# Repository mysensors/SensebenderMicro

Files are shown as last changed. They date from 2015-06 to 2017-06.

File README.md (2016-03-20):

# Sensebender Micro

This is a micro sensor module for Mysensors project: http://www.mysensors.org

Designed to run on 2 x AA(A) batteries, depending on how often one would
like to replace the batteries. 

The sensor includes the following peripherals

- Si7021 Temperature / Humidity sensor (Connected to I2C bus)
- Jedec compatible eeprom/flash footprint
- ATSHA204A for authentication
- LED

The following pins are available on headers:

- Powersupply (1.8 -> 3.5V)
- SDA / SCL (I2C bus)
- A0 / A1
- D3 / D4 / D5 / D6 / D7
- 6 pin ISP port
- 8 pin standard NRF24L01+ connector layout
- FTDI header for serial

*Please note*

MAXIMUM allowed supply voltage is 3.5V, anything above this WILL fry both
Si7021, flash and NRF24 radio module. There is NO voltage regulator on board (To keep
supply current down to a minimum)

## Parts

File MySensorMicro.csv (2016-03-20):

Qty | Value | Device | Package | Parts | Description | MF | MPN
1 |  | LED-0402 | LED-0402 | D1 |  | Vishay | VLMO1500-GS08
0 | NM | M05NO_SILK | 1X05_NO_SILK | JP4 | Not mounted
0 | NM | M06NO_SILK_FEMALE_PTH | 1X06_NO_SILK | JP2, JP5 | Not mounted
5 | 100n | CAP-0402 | C0402 | C1, C2, C4, C5, C6 | Ceramic Capacitors
1 | 10k | R-0402 | R0402 | R3
0 | 32768hz | CRYSTAL-306010055 | 2P-L3.2XW1.5MM | Q1 | Not mounted
1 | 330 | R-0402 | R0402 | R4
2 | 4k7 | R-0402 | R0402 | R1, R2
2 | 56k | R-0402 | R0402 | R5, R6
1 | 4u7 | CAP-0603 | C0603 | C3 | Ceramic Capacitors
1 | AT25DF512C-SSHN-B | AT25DF512C-SSHN-B | SO-08 | IC2 | Flash 512K, 1.65V, 85Mhz Serial Flash | Adesto | AT25DF512C-SSHN-B
1 | ATSHA204A | ATSHA204A | SOT23 | IC4 |  | Atmel | ATSHA204A-STUCZ-T
0 | NM | AVR-ISP-6VERT | AVR-ISP-6 | JP3 | Not mounted
1 | MEGA328P-AU | MEGA48/88/168-AU | TQFP32-08 | IC1 |  | Atmel | ATMEGA328P-AU
0 | NM | PINHD-2X4 | 2X04 | JP1 | Not mounted
1 | SI7021 | SI7021 | DFN6 | IC3 |  | Silicon Labs | Si7021-A20-GM1

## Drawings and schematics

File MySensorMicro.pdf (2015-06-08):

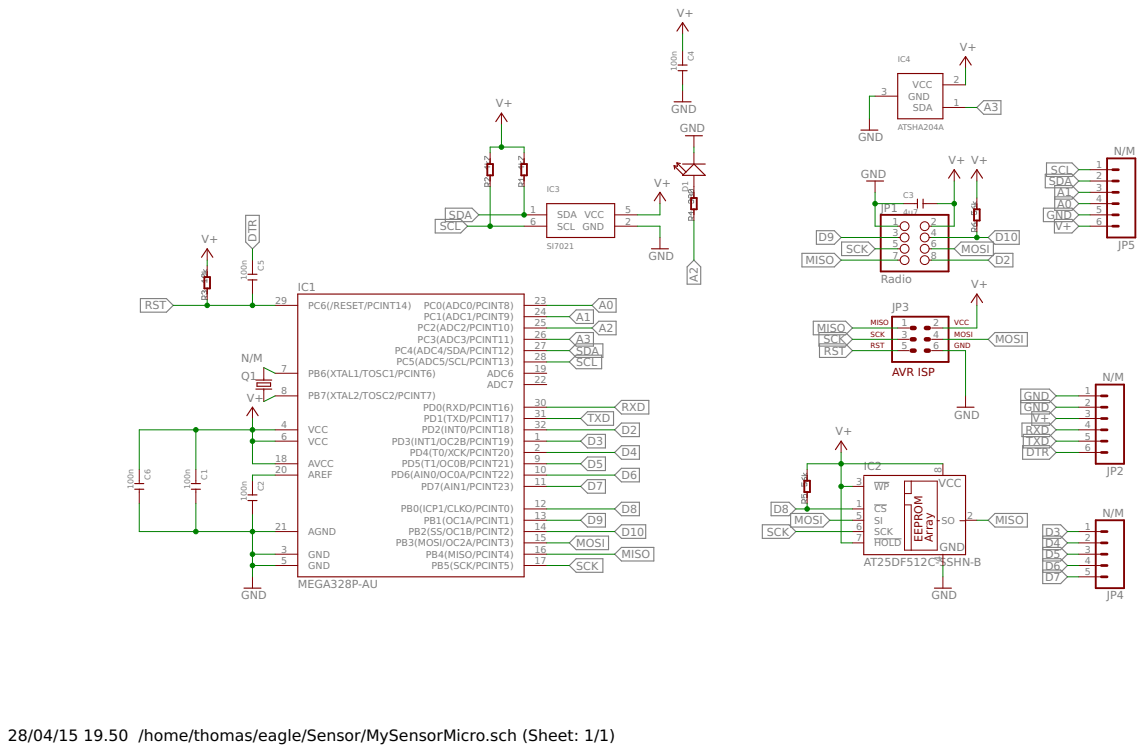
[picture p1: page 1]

2 HOLD

28/04/15 19.50 /home/thomas/eagle/Sensor/MySensorMicro.sch (Sheet: 1/1)

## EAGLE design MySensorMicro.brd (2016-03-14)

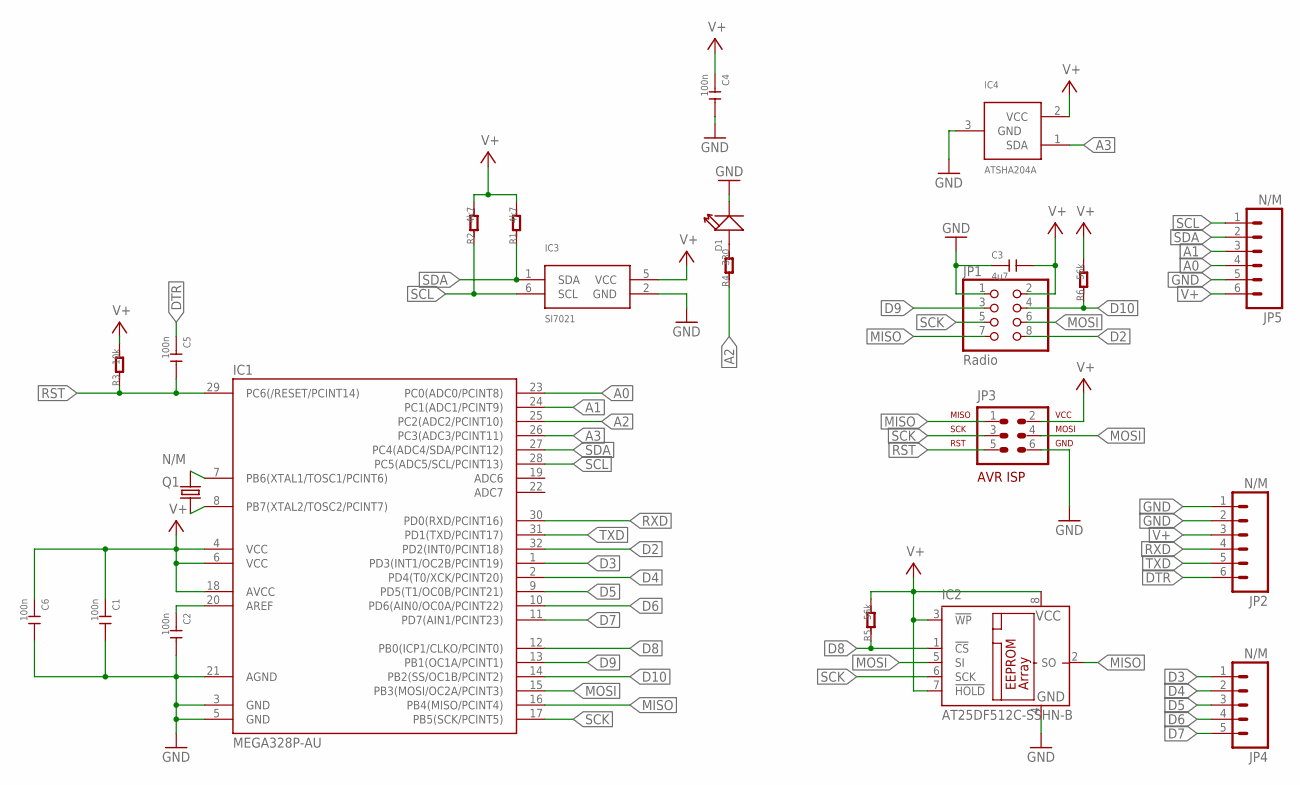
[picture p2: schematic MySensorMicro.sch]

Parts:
C1, C2, C4, C5, C6: 100n; C0402
C3: 4u7; C0603
D1: LED-0402
IC1: MEGA328P-AU; TQFP32-08
IC2: AT25DF512C-SSHN-B; SO-08
IC3: SI7021; DFN6
IC4: ATSHA204A; SOT23
JP1: Radio; 2X04
JP2, JP5: N/M; 1X06_NO_SILK
JP3: N/M; AVR-ISP-6
JP4: N/M; 1X05_NO_SILK
Q1: N/M; 2P-L3.2XW1.5MM
R1, R2: 4k7; R0402
R3: 10k; R0402
R4: 330; R0402
R5, R6: 56k; R0402

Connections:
A0: IC1.23 (PC0(ADC0/PCINT8)), JP5.4
A1: IC1.24 (PC1(ADC1/PCINT9)), JP5.3
A2: IC1.25 (PC2(ADC2/PCINT10)), R4.1
A3: IC1.26 (PC3(ADC3/PCINT11)), IC4.1 (SDA)
D2: IC1.32 (PD2(INT0/PCINT18)), JP1.8
D3: IC1.1 (PD3(INT1/OC2B/PCINT19)), JP4.1
D4: IC1.2 (PD4(T0/XCK/PCINT20)), JP4.2
D5: IC1.9 (PD5(T1/OC0B/PCINT21)), JP4.3
D6: IC1.10 (PD6(AIN0/OC0A/PCINT22)), JP4.4
D7: IC1.11 (PD7(AIN1/PCINT23)), JP4.5
D8: IC1.12 (PB0(ICP1/CLKO/PCINT0)), IC2.1 (!CS), R5.1
D9: IC1.13 (PB1(OC1A/PCINT1)), JP1.3
D10: IC1.14 (PB2(SS/OC1B/PCINT2)), JP1.4, R6.1
DTR: C5.1, JP2.6
GND: C1.2, C2.2, C3.1, C4.2, C6.2, D1.-, IC1.3 (GND), IC1.5 (GND), IC1.21 (AGND), IC2.4 (GND), IC3.2 (GND), IC4.3 (GND), JP1.1, JP2.1, JP2.2, JP3.6, JP5.5
MISO: IC1.16 (PB4(MISO/PCINT4)), IC2.2 (SO), JP1.7, JP3.1
MOSI: IC1.15 (PB3(MOSI/OC2A/PCINT3)), IC2.5 (SI), JP1.6, JP3.4
unnamed: IC1.7 (PB6(XTAL1/TOSC1/PCINT6)), Q1.1
unnamed: IC1.8 (PB7(XTAL2/TOSC2/PCINT7)), Q1.2
unnamed: D1.+, R4.2
unnamed: C2.1, IC1.20 (AREF)
RST: C5.2, IC1.29 (PC6(/RESET/PCINT14)), JP3.5, R3.1
RXD: IC1.30 (PD0(RXD/PCINT16)), JP2.4
SCK: IC1.17 (PB5(SCK/PCINT5)), IC2.6 (SCK), JP1.5, JP3.3
SCL: IC1.28 (PC5(ADC5/SCL/PCINT13)), IC3.6 (SCL), JP5.1, R2.1
SDA: IC1.27 (PC4(ADC4/SDA/PCINT12)), IC3.1 (SDA), JP5.2, R1.1
TXD: IC1.31 (PD1(TXD/PCINT17)), JP2.5
V+: C1.1, C3.2, C4.1, C6.1, IC1.4 (VCC), IC1.6 (VCC), IC1.18 (AVCC), IC2.3 (!WP), IC2.7 (!HOLD), IC2.8 (VCC), IC3.5 (VCC), IC4.2 (VCC), JP1.2, JP2.3, JP3.2, JP5.6, R1.2, R2.2, R3.2, R5.2, R6.2

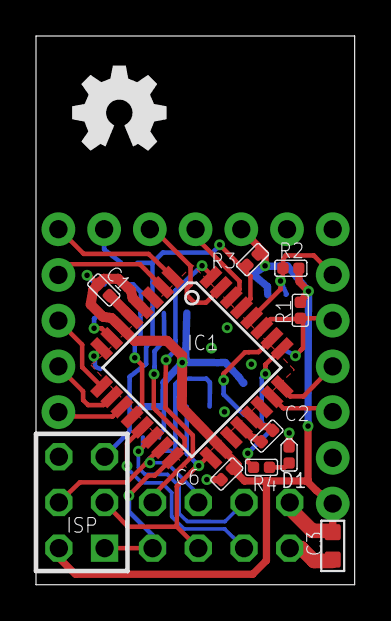
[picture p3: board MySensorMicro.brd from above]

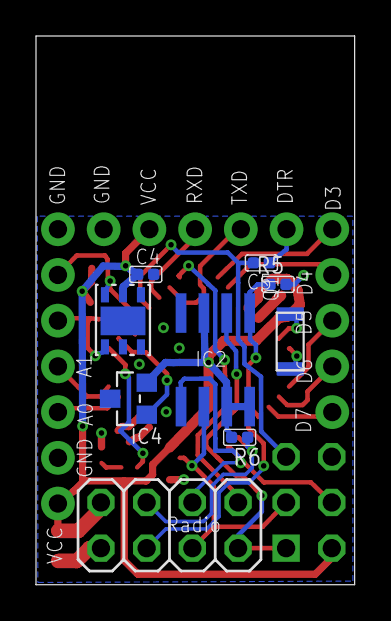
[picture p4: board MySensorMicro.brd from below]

Board: 2 copper layers, 17.7 x 30.5 mm, 23 parts (9 on the bottom side), 28 nets.

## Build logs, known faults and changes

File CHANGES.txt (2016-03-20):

commit 12a186989da0a213372178e72b3d47e3f46b5c39
Author: Thomas Mørch <thomas@bowmo.dk>
Date:   Sun Mar 20 11:03:00 2016 +0100

    Added license files

commit 9c6fbff83cbd732324b70228c96c489922747ecb
Author: Thomas Mørch <thomas@bowmo.dk>
Date:   Sun Mar 20 08:44:23 2016 +0100

    Corrected readme file

commit 1925091e317b5627f6f4a252ab48d5a810d345f4
Author: Thomas Mørch <thomas@bowmo.dk>
Date:   Sun Mar 20 08:39:12 2016 +0100

    Added BOM file

commit ceea0fcb51a1bdef3b00939cef161c32a42b2b1d
Merge: b7491d6 e9a2936
Author: Thomas Mørch <tbowmo@users.noreply.github.com>
Date:   Mon Mar 14 10:12:15 2016 +0100

    Merge pull request #2 from AhmedAdelHosni/master
    
    Updated component values on R5/R6

commit e9a29362c966621333c1182c153e39e1da846b3a
Author: AhmedAdelHosni <ahmed.adel.hosni@gmail.com>
Date:   Sun Mar 13 22:54:48 2016 +0200

    Updated component values on R5/R6
    
    Fix error > Board and schematic are not consistent! No
    forward-/backannotation will be performed!
    Changes are done using Eagle 7.3.0

commit b7491d6ed4ddf0a060c874108f0a5083b8e7cc7f
Merge: 702167a cc55a6e
Author: Henrik Ekblad <henrik.ekblad@gmail.com>
Date:   Mon Jun 8 21:23:42 2015 +0200

    Merge pull request #1 from tbowmo/master
    
    Merge latest

commit cc55a6e985fc09cfe503e1d9673b94dc9aa92421
Merge: 7a72637 702167a
Author: Thomas Mørch <tbowmo@users.noreply.github.com>
Date:   Mon Jun 8 21:17:59 2015 +0200

    Merge pull request #1 from mysensors/master
    
    Updated name

commit 7a72637da3a2cb4125ce89c6f3736f20ab1a45a8
Author: Thomas Mørch <thomas@bowmo.dk>
Date:   Mon Jun 8 21:03:33 2015 +0200

    Added pdf of schematic

commit 702167a173d682caa59032d1dbbb1c58191e162d
Author: Henrik Ekblad <henrik.ekblad@gmail.com>
Date:   Sun May 3 14:57:36 2015 +0200

    Updated name

commit 6f9d441785c2c0ee8364f5e353a31250fb7f7e91
Author: Thomas Mørch <thomas@bowmo.dk>
Date:   Tue Apr 28 20:54:06 2015 +0200

    Updated component values on R5/R6

commit a9658f6beb4978a6db89c47790608973ae35b67d
Author: Thomas Mørch <thomas@bowmo.dk>
Date:   Thu Apr 9 19:41:53 2015 +0200

    Updated with pullup on both CSN on NRF module, and CE on external flash

commit 80aa3bc2c3508a25c7a4644aab8bf5bd5ac3c78c
Author: Thomas Mørch <thomas@bowmo.dk>
Date:   Wed Apr 1 10:21:22 2015 +0200

    Updated board layout

commit 79ec694619c472c08962edfc25b17c7105b51f81
Author: Thomas Mørch <thomas@bowmo.dk>
Date:   Sun Mar 1 11:02:13 2015 +0100

    Updated part number for external flash

commit 2e32f2f1a14e2fc806389f1ae394f1060c63ea62
Author: Thomas Mørch <thomas@bowmo.dk>
Date:   Wed Jan 28 19:46:06 2015 +0100

    Updated with graphics, sendt to dirtypcbs.com for manufacturing

commit a41e8fde1bd1568f0d2d8a725a92187eeb6135e8
Author: Thomas Mørch <thomas@bowmo.dk>
Date:   Sun Jan 25 20:23:07 2015 +0100

    Cleaned up routing here and there, moved crystal slightly..

commit 8b9f0619e0f77194aeeb1ce134e5cf3d9e13da76
Author: Thomas Mørch <thomas@bowmo.dk>
Date:   Sun Jan 25 18:12:39 2015 +0100

    Updated README file

commit 08fb1947a0c60a256ce0a585195b0592fe95ff87
Author: Thomas Mørch <thomas@bowmo.dk>
Date:   Sun Jan 25 15:02:41 2015 +0100

    Updated readme file

commit 243aa970c42215cd80159821185e0518ee0d3b80
Author: Thomas Mørch <thomas@bowmo.dk>
Date:   Sun Jan 25 14:55:38 2015 +0100

    Initial commit

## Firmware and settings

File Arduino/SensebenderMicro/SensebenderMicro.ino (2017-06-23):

/**
 * The MySensors Arduino library handles the wireless radio link and protocol
 * between your home built sensors/actuators and HA controller of choice.
 * The sensors forms a self healing radio network with optional repeaters. Each
 * repeater and gateway builds a routing tables in EEPROM which keeps track of the
 * network topology allowing messages to be routed to nodes.
 *
 * Created by Henrik Ekblad <henrik.ekblad@mysensors.org>
 * Copyright (C) 2013-2015 Sensnology AB
 * Full contributor list: https://github.com/mysensors/Arduino/graphs/contributors
 *
 * Documentation: http://www.mysensors.org
 * Support Forum: http://forum.mysensors.org
 *
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
 *******************************
 *
 * REVISION HISTORY
 * Version 1.0 - Thomas Bowman Mørch
 * 
 * DESCRIPTION
 * Default sensor sketch for Sensebender Micro module
 * Act as a temperature / humidity sensor by default.
 *
 * If A0 is held low while powering on, it will enter testmode, which verifies all on-board peripherals
 *  
 * Battery voltage is as battery percentage (Internal message), and optionally as a sensor value (See defines below)
 *
 *
 * Version 1.3 - Thomas Bowman Mørch
 * Improved transmission logic, eliminating spurious transmissions (when temperatuere / humidity fluctuates 1 up and down between measurements) 
 * Added OTA boot mode, need to hold A1 low while applying power. (uses slightly more power as it's waiting for bootloader messages)
 * 
 * Version 1.4 - Thomas Bowman Mørch
 * 
 * Corrected division in the code deciding whether to transmit or not, that resulted in generating an integer. Now it's generating floats as expected.
 * Simplified detection for OTA bootloader, now detecting if MY_OTA_FIRMWARE_FEATURE is defined. If this is defined sensebender automaticly waits 300mS after each transmission
 * Moved Battery status messages, so they are transmitted together with normal sensor updates (but only every 60th minute)
 * 
 */

// Enable debug prints to serial monitor
//#define MY_DEBUG 

// Define a static node address, remove if you want auto address assignment
//#define MY_NODE_ID 3

// Enable and select radio type attached
#define MY_RADIO_NRF24
//#define MY_RADIO_RFM69

// Enable to support OTA for this node (needs DualOptiBoot boot-loader to fully work)
#define MY_OTA_FIRMWARE_FEATURE

#include <SPI.h>
#include <MySensors.h>
#include <Wire.h>
#include <SI7021.h>
#ifndef MY_OTA_FIRMWARE_FEATURE
#include "drivers/SPIFlash/SPIFlash.cpp"
#endif
#include <EEPROM.h>  
#include <sha204_lib_return_codes.h>
#include <sha204_library.h>
#include <RunningAverage.h>
//#include <avr/power.h>

// Uncomment the line below, to transmit battery voltage as a normal sensor value
//#define BATT_SENSOR    199

#define RELEASE "1.4"

#define AVERAGES 2

// Child sensor ID's
#define CHILD_ID_TEMP  1
#define CHILD_ID_HUM   2

// How many milli seconds between each measurement
#define MEASURE_INTERVAL 60000

// How many milli seconds should we wait for OTA?
#define OTA_WAIT_PERIOD 300

// FORCE_TRANSMIT_INTERVAL, this number of times of wakeup, the sensor is forced to report all values to the controller
#define FORCE_TRANSMIT_INTERVAL 30 

// When MEASURE_INTERVAL is 60000 and FORCE_TRANSMIT_INTERVAL is 30, we force a transmission every 30 minutes.
// Between the forced transmissions a tranmission will only occur if the measured value differs from the previous measurement

// HUMI_TRANSMIT_THRESHOLD tells how much the humidity should have changed since last time it was transmitted. Likewise with
// TEMP_TRANSMIT_THRESHOLD for temperature threshold.
#define HUMI_TRANSMIT_THRESHOLD 0.5
#define TEMP_TRANSMIT_THRESHOLD 0.5

// Pin definitions
#define TEST_PIN       A0
#define LED_PIN        A2
#define ATSHA204_PIN   17 // A3

const int sha204Pin = ATSHA204_PIN;
atsha204Class sha204(sha204Pin);

SI7021 humiditySensor;
SPIFlash flash(8, 0x1F65);

// Sensor messages
MyMessage msgHum(CHILD_ID_HUM, V_HUM);
MyMessage msgTemp(CHILD_ID_TEMP, V_TEMP);

#ifdef BATT_SENSOR
MyMessage msgBatt(BATT_SENSOR, V_VOLTAGE);
#endif

// Global settings
int measureCount = 0;
int sendBattery = 0;
boolean isMetric = true;
boolean highfreq = true;
boolean transmission_occured = false;

// Storage of old measurements
float lastTemperature = -100;
int lastHumidity = -100;
long lastBattery = -100;

RunningAverage raHum(AVERAGES);

/****************************************************
 *
 * Setup code 
 *
 ****************************************************/
void setup() {
  
  pinMode(LED_PIN, OUTPUT);
  digitalWrite(LED_PIN, LOW);

  Serial.begin(115200);
  Serial.print(F("Sensebender Micro FW "));
  Serial.print(RELEASE);
  Serial.flush();

  // First check if we should boot into test mode

  pinMode(TEST_PIN,INPUT);
  digitalWrite(TEST_PIN, HIGH); // Enable pullup
  if (!digitalRead(TEST_PIN)) testMode();

  // Make sure that ATSHA204 is not floating
  pinMode(ATSHA204_PIN, INPUT);
  digitalWrite(ATSHA204_PIN, HIGH);
  
  digitalWrite(TEST_PIN,LOW);
  
  digitalWrite(LED_PIN, HIGH); 

  humiditySensor.begin();

  digitalWrite(LED_PIN, LOW);

  Serial.flush();
  Serial.println(F(" - Online!"));
  
  isMetric = getControllerConfig().isMetric;
  Serial.print(F("isMetric: ")); Serial.println(isMetric);
  raHum.clear();
  sendTempHumidityMeasurements(false);
  sendBattLevel(false);
  
#ifdef MY_OTA_FIRMWARE_FEATURE  
  Serial.println("OTA FW update enabled");
#endif

}

void presentation()  {
  sendSketchInfo("Sensebender Micro", RELEASE);

  present(CHILD_ID_TEMP,S_TEMP);
  present(CHILD_ID_HUM,S_HUM);
    
#ifdef BATT_SENSOR
  present(BATT_SENSOR, S_POWER);
#endif
}


/***********************************************
 *
 *  Main loop function
 *
 ***********************************************/
void loop() {
  
  measureCount ++;
  sendBattery ++;
  bool forceTransmit = false;
  transmission_occured = false;
  
  if (measureCount >= FORCE_TRANSMIT_INTERVAL) { // force a transmission
    forceTransmit = true; 
    measureCount = 0;
  }
    
  sendTempHumidityMeasurements(forceTransmit);
/*  if (sendBattery > 60) 
  {
     sendBattLevel(forceTransmit); // Not needed to send battery info that often
     sendBattery = 0;
  }*/
#ifdef MY_OTA_FIRMWARE_FEATURE
  if (transmission_occured) {
      wait(OTA_WAIT_PERIOD);
  }
#endif

  sleep(MEASURE_INTERVAL);  
}


/*********************************************
 *
 * Sends temperature and humidity from Si7021 sensor
 *
 * Parameters
 * - force : Forces transmission of a value (even if it's the same as previous measurement)
 *
 *********************************************/
void sendTempHumidityMeasurements(bool force)
{
  bool tx = force;

  si7021_env data = humiditySensor.getHumidityAndTemperature();
  
  raHum.addValue(data.humidityPercent);
  
  float diffTemp = abs(lastTemperature - (isMetric ? data.celsiusHundredths : data.fahrenheitHundredths)/100.0);
  float diffHum = abs(lastHumidity - raHum.getAverage());

  Serial.print(F("TempDiff :"));Serial.println(diffTemp);
  Serial.print(F("HumDiff  :"));Serial.println(diffHum); 

  if (isnan(diffHum)) tx = true; 
  if (diffTemp >= TEMP_TRANSMIT_THRESHOLD) tx = true;
  if (diffHum >= HUMI_TRANSMIT_THRESHOLD) tx = true;

  if (tx) {
    measureCount = 0;
    float temperature = (isMetric ? data.celsiusHundredths : data.fahrenheitHundredths) / 100.0;
     
    int humidity = data.humidityPercent;
    Serial.print("T: ");Serial.println(temperature);
    Serial.print("H: ");Serial.println(humidity);
    
    send(msgTemp.set(temperature,1));
    send(msgHum.set(humidity));
    lastTemperature = temperature;
    lastHumidity = humidity;
    transmission_occured = true;
    if (sendBattery > 60) {
     sendBattLevel(true); // Not needed to send battery info that often
     sendBattery = 0;
    }
  }
}

/********************************************
 *
 * Sends battery information (battery percentage)
 *
 * Parameters
 * - force : Forces transmission of a value
 *
 *******************************************/
void sendBattLevel(bool force)
{
  if (force) lastBattery = -1;
  long vcc = readVcc();
  if (vcc != lastBattery) {
    lastBattery = vcc;

#ifdef BATT_SENSOR
    float send_voltage = float(vcc)/1000.0f;
    send(msgBatt.set(send_voltage,3));
#endif

    // Calculate percentage

    vcc = vcc - 1900; // subtract 1.9V from vcc, as this is the lowest voltage we will operate at
    
    long percent = vcc / 14.0;
    sendBatteryLevel(percent);
    transmission_occured = true;
  }
}

/*******************************************
 *
 * Internal battery ADC measuring 
 *
 *******************************************/
long readVcc() {
  // Read 1.1V reference against AVcc
  // set the reference to Vcc and the measurement to the internal 1.1V reference
  #if defined(__AVR_ATmega32U4__) || defined(__AVR_ATmega1280__) || defined(__AVR_ATmega2560__)
    ADMUX = _BV(REFS0) | _BV(MUX4) | _BV(MUX3) | _BV(MUX2) | _BV(MUX1);
  #elif defined (__AVR_ATtiny24__) || defined(__AVR_ATtiny44__) || defined(__AVR_ATtiny84__)
    ADMUX = _BV(MUX5) | _BV(MUX0);
  #elif defined (__AVR_ATtiny25__) || defined(__AVR_ATtiny45__) || defined(__AVR_ATtiny85__)
    ADcdMUX = _BV(MUX3) | _BV(MUX2);
  #else
    ADMUX = _BV(REFS0) | _BV(MUX3) | _BV(MUX2) | _BV(MUX1);
  #endif  
 
  delay(2); // Wait for Vref to settle
  ADCSRA |= _BV(ADSC); // Start conversion
  while (bit_is_set(ADCSRA,ADSC)); // measuring
 
  uint8_t low  = ADCL; // must read ADCL first - it then locks ADCH  
  uint8_t high = ADCH; // unlocks both
 
  long result = (high<<8) | low;
 
  result = 1125300L / result; // Calculate Vcc (in mV); 1125300 = 1.1*1023*1000
  return result; // Vcc in millivolts
 
}

/****************************************************
 *
 * Verify all peripherals, and signal via the LED if any problems.
 *
 ****************************************************/
void testMode()
{
  uint8_t rx_buffer[SHA204_RSP_SIZE_MAX];
  uint8_t ret_code;
  byte tests = 0;
  
  digitalWrite(LED_PIN, HIGH); // Turn on LED.
  Serial.println(F(" - TestMode"));
  Serial.println(F("Testing peripherals!"));
  Serial.flush();
  Serial.print(F("-> SI7021 : ")); 
  Serial.flush();
  
  if (humiditySensor.begin()) 
  {
    Serial.println(F("ok!"));
    tests ++;
  }
  else
  {
    Serial.println(F("failed!"));
  }
  Serial.flush();

  Serial.print(F("-> Flash : "));
  Serial.flush();
  if (flash.initialize())
  {
    Serial.println(F("ok!"));
    tests ++;
  }
  else
  {
    Serial.println(F("failed!"));
  }
  Serial.flush();

  
  Serial.print(F("-> SHA204 : "));
  ret_code = sha204.sha204c_wakeup(rx_buffer);
  Serial.flush();
  if (ret_code != SHA204_SUCCESS)
  {
    Serial.print(F("Failed to wake device. Response: ")); Serial.println(ret_code, HEX);
  }
  Serial.flush();
  if (ret_code == SHA204_SUCCESS)
  {
    ret_code = sha204.getSerialNumber(rx_buffer);
    if (ret_code != SHA204_SUCCESS)
    {
      Serial.print(F("Failed to obtain device serial number. Response: ")); Serial.println(ret_code, HEX);
    }
    else
    {
      Serial.print(F("Ok (serial : "));
      for (int i=0; i<9; i++)
      {
        if (rx_buffer[i] < 0x10)
        {
          Serial.print('0'); // Because Serial.print does not 0-pad HEX
        }
        Serial.print(rx_buffer[i], HEX);
      }
      Serial.println(")");
      tests ++;
    }

  }
  Serial.flush();

  Serial.println(F("Test finished"));
  
  if (tests == 3) 
  {
    Serial.println(F("Selftest ok!"));
    while (1) // Blink OK pattern!
    {
      digitalWrite(LED_PIN, HIGH);
      delay(200);
      digitalWrite(LED_PIN, LOW);
      delay(200);
    }
  }
  else 
  {
    Serial.println(F("----> Selftest failed!"));
    while (1) // Blink FAILED pattern! Rappidly blinking..
    {
    }
  }  
}

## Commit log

2015-01-25 Cleaned up routing here and there, moved crystal slightly..
    [MySensorMicro.brd]
2015-01-28 Updated with graphics, sendt to dirtypcbs.com for manufacturing
    [MySensorMicro.brd]
2015-03-01 Updated part number for external flash
    [MySensorMicro.brd, MySensorMicro.sch]
2015-04-01 Updated board layout
    [MySensorMicro.brd]
2015-04-09 Updated with pullup on both CSN on NRF module, and CE on external flash
    [MySensorMicro.brd, MySensorMicro.sch]
2015-04-28 Updated component values on R5/R6
    [MySensorMicro.sch]
2015-06-08 Added pdf of schematic
2016-03-13 Updated component values on R5/R6
    Fix error > Board and schematic are not consistent! No
    forward-/backannotation will be performed!
    Changes are done using Eagle 7.3.0
    [MySensorMicro.brd]
2016-03-20 Added BOM file
    [MySensorMicro.csv]
2017-01-23 Fix controller config api change
    [SensebenderMicro.ino]
2017-05-13 Make sure data are sent as expected
    1)Before the fix it took 1 more cycle than expected before the data were sent. Corrected now.
    2)Small fix in threshold checking
    [SensebenderMicro.ino]
2017-06-13 Removed low frequency operation
    the switch to lower frequency operation is not needed, as the battery life is not reduced dramatically, and it confuses users more than necessary, when communication is borked after aprox. 5 minutes due to changes to the oscillator frequency.
    [SensebenderMicro.ino]

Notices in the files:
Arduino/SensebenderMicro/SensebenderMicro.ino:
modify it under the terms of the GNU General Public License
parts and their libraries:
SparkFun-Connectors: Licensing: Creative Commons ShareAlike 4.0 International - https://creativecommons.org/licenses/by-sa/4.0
